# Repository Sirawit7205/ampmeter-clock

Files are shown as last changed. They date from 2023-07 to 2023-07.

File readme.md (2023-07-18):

# Ammeter Clock Controller

This is an open-source KiCAD 5 design files for a logic chips-driven clock that output time on three ammeters.

## Pictures

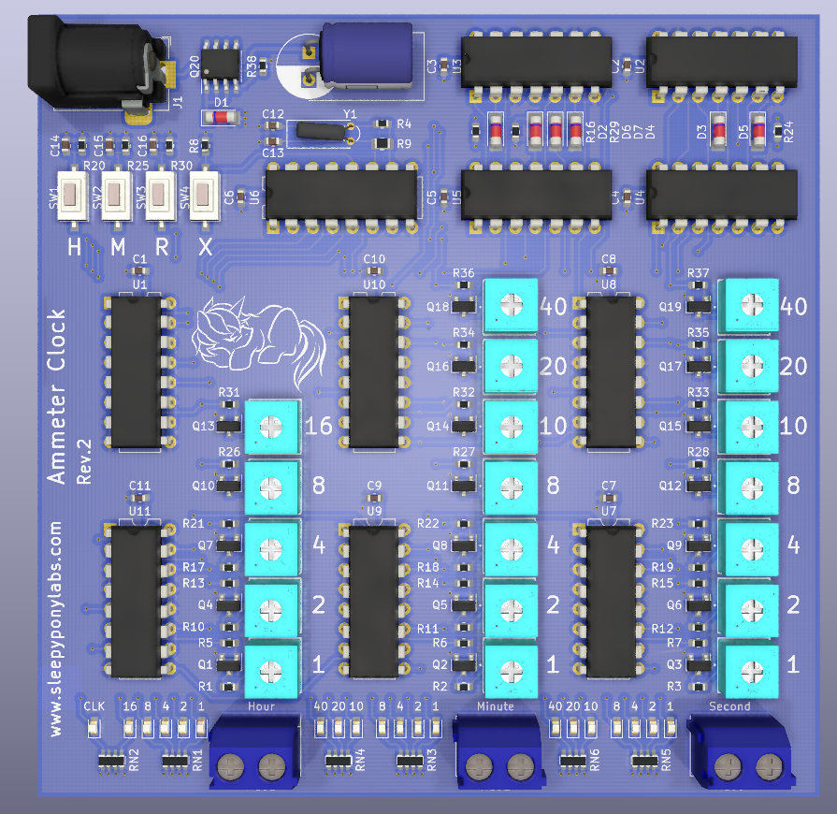
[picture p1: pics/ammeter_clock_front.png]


## Features

This is a unique clock that will certainly impress people around you.

- Ammeter Output
	- Shows hour, minute, and second on three ammeters.
	- Works with both analog and digital meters.
- Quartz Crystal-driven Clock with CD4060 IC
- Design with logic ICs. Only need 11 chips for the circuit to work.
- Set Hour, Set Min, Reset, and Clock Halt buttons
- Ammeter adjustment trimpots
- Aluminum Front Panel design available [here](https://github.com/Sirawit7205/ammeter-clock-frontpanel)

## Revisions

We are currently at Revision 2. Changelog is below:

**Revision 1 (July 2021)**
- Initial Design
- H and M buttons are swapped.

**Revision 2 (September 2021)**
- Fix H and M buttons.

## What is provided

The goal of this repository is to enable you to build this on your own as easy as possible. **The schematics, PCB design, and an interactive BOM are provided.**

Hardware is licensed under `SPDX-License-Identifier: CERN-OHL-S-2.0`

Contains no software

Documentation is licensed under `SPDX-License-Identifier: CC-BY-SA-4.0`

## Ordering

You can export gerbers from this project and order the board yourself.

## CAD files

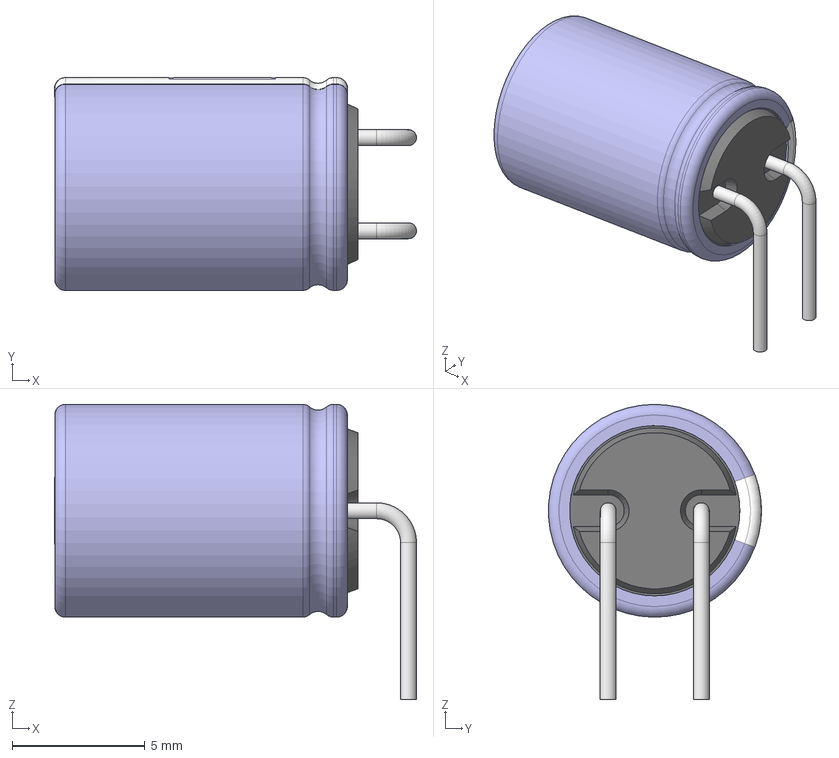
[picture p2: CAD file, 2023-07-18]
3dmodels/cap_el_horizontal_d8_h11.5_pitch3.5_w0.6.stp
13.6 x 8.00 x 11.1 mm

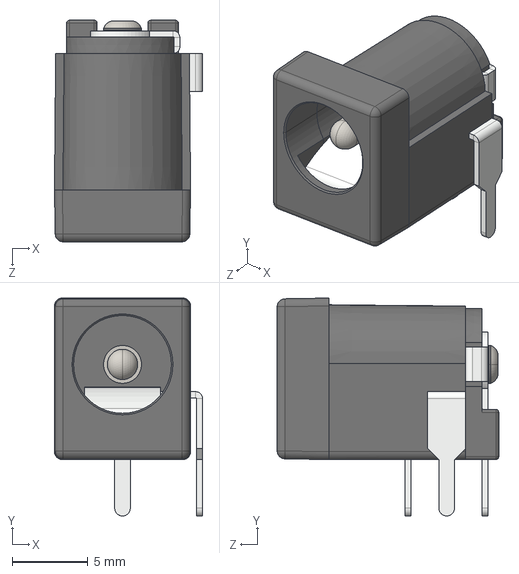
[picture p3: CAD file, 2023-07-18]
3dmodels/DC Power Jack 5.5mm x 2.1mm.STEP
9.77 x 14.4 x 14.6 mm

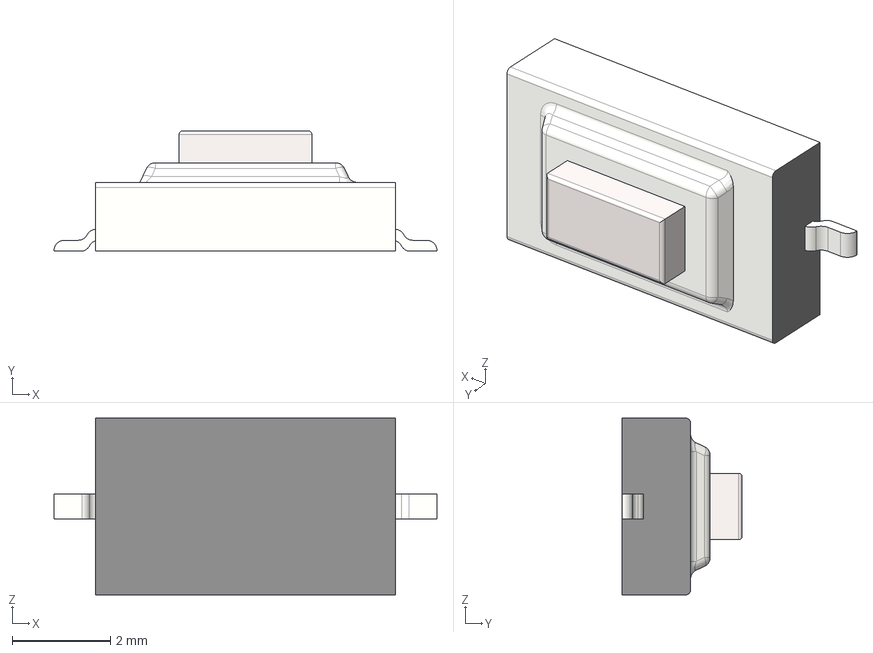
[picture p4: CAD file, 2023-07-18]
3dmodels/TactileButton(6x3,5mm)_SMD.stp
7.80 x 2.45 x 3.60 mm

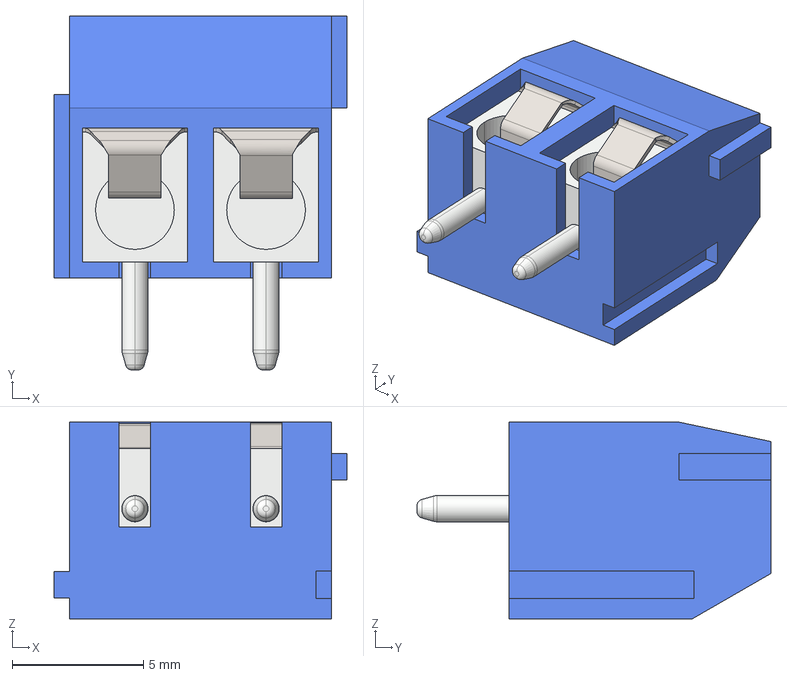
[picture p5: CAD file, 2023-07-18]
3dmodels/TE_1776244-2.STEP
11.2 x 13.5 x 7.50 mm

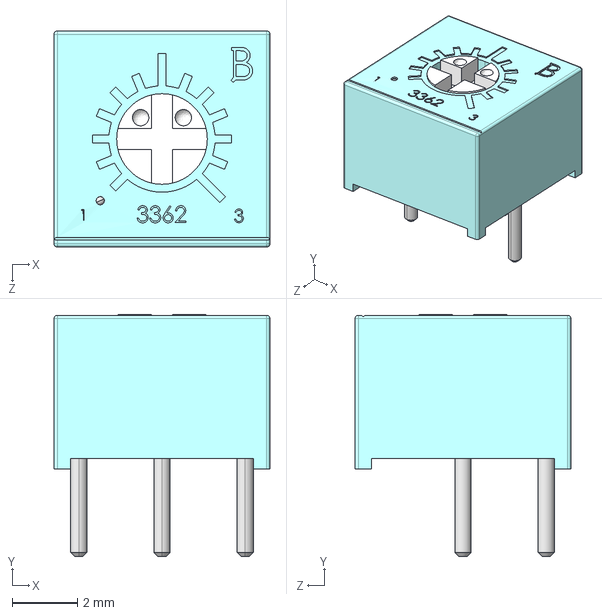
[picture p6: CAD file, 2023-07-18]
3dmodels/3362P-1-102LF.STEP
6.60 x 7.40 x 6.60 mm

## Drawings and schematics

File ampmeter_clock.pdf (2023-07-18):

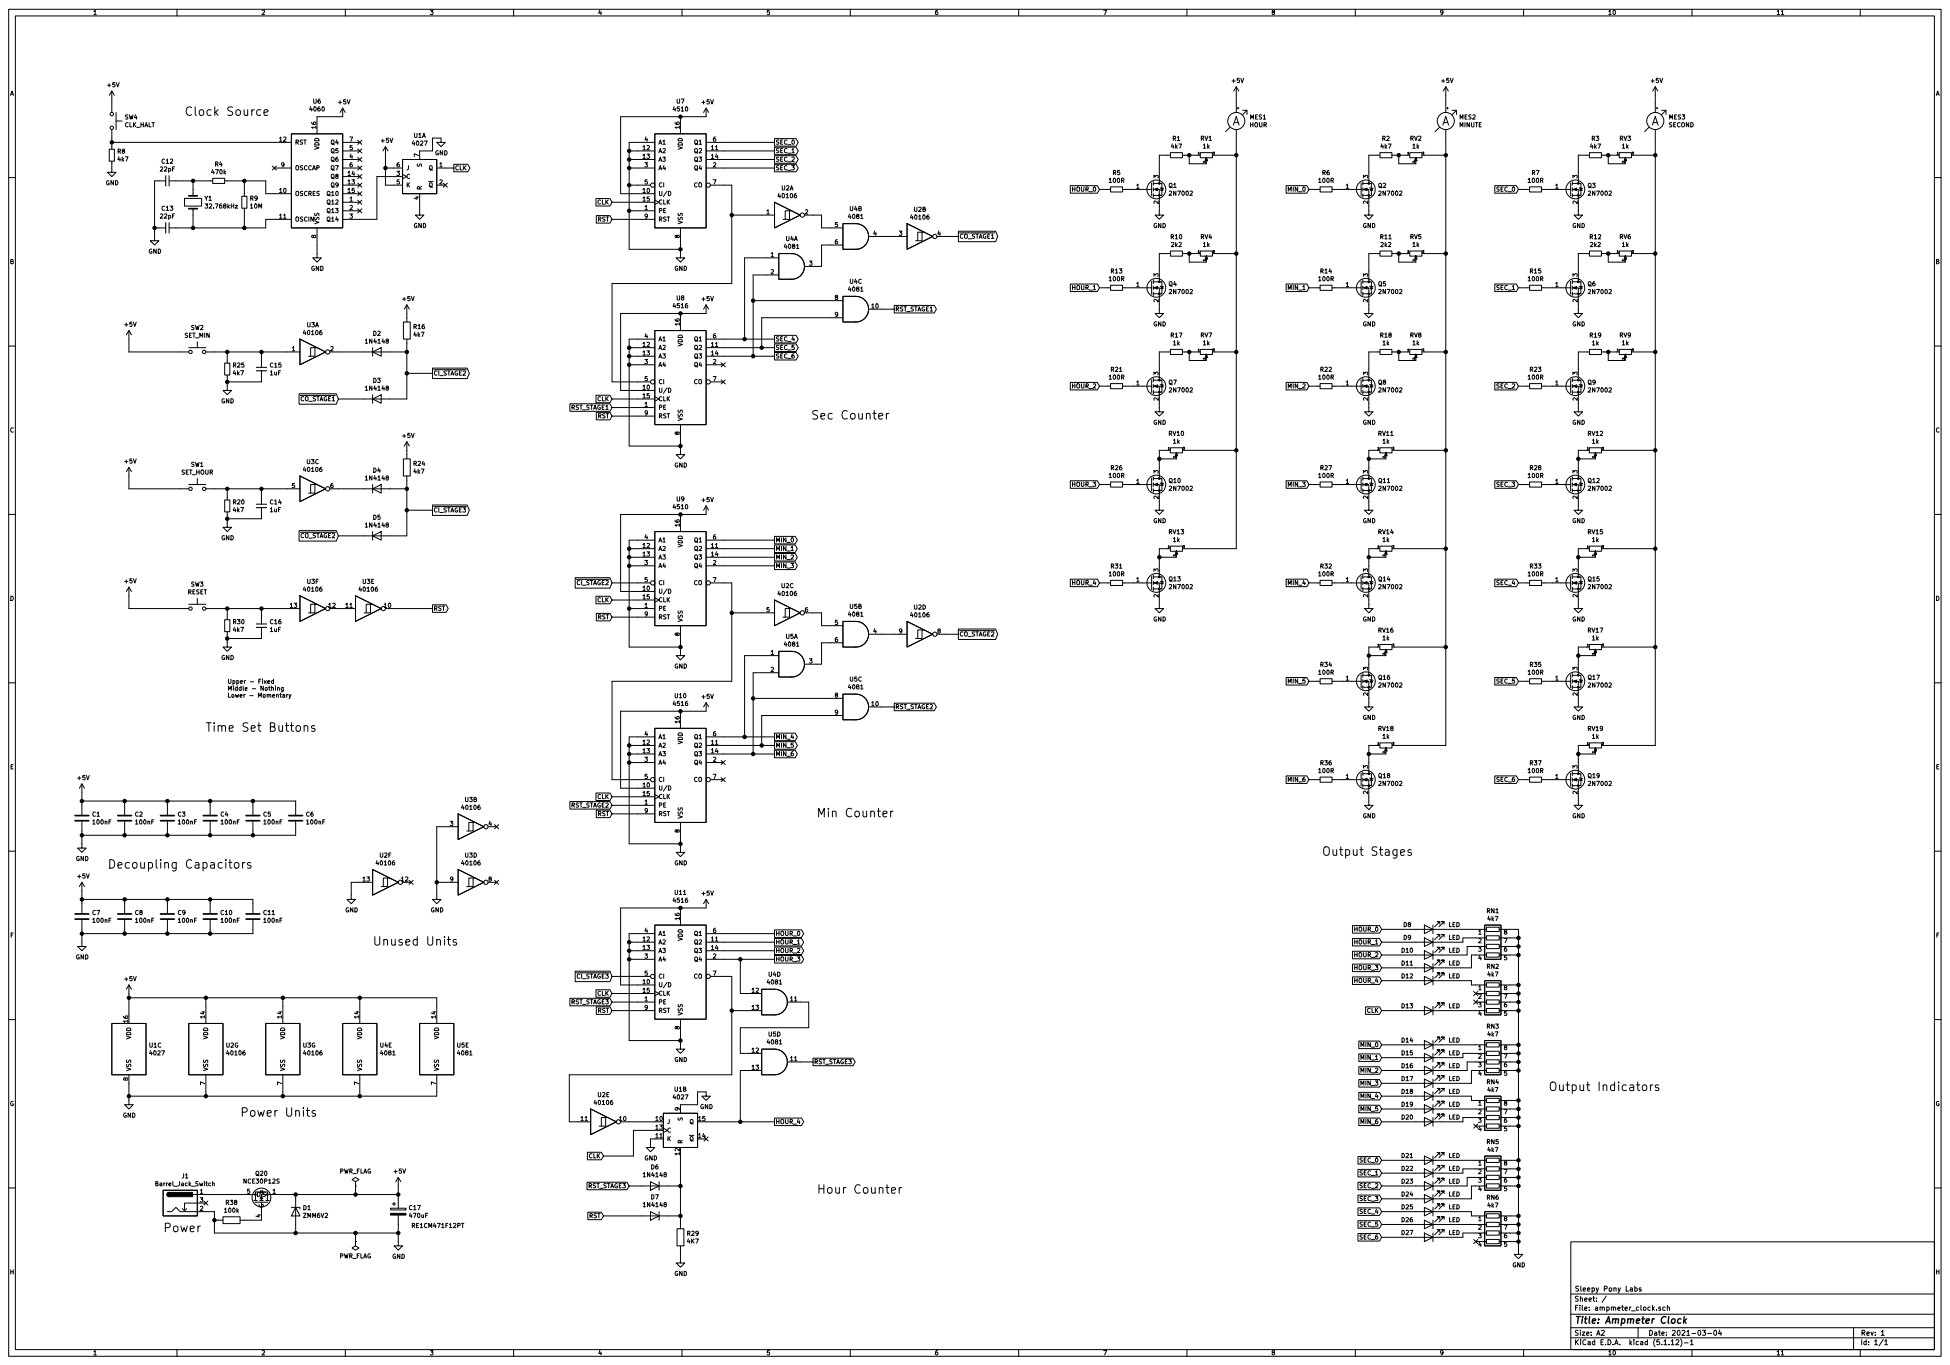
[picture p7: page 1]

File: ampmeter_clock.sch Sheet: / Sleepy Pony Labs A
GND

Id: 1/1 Title: Ampmeter Clock

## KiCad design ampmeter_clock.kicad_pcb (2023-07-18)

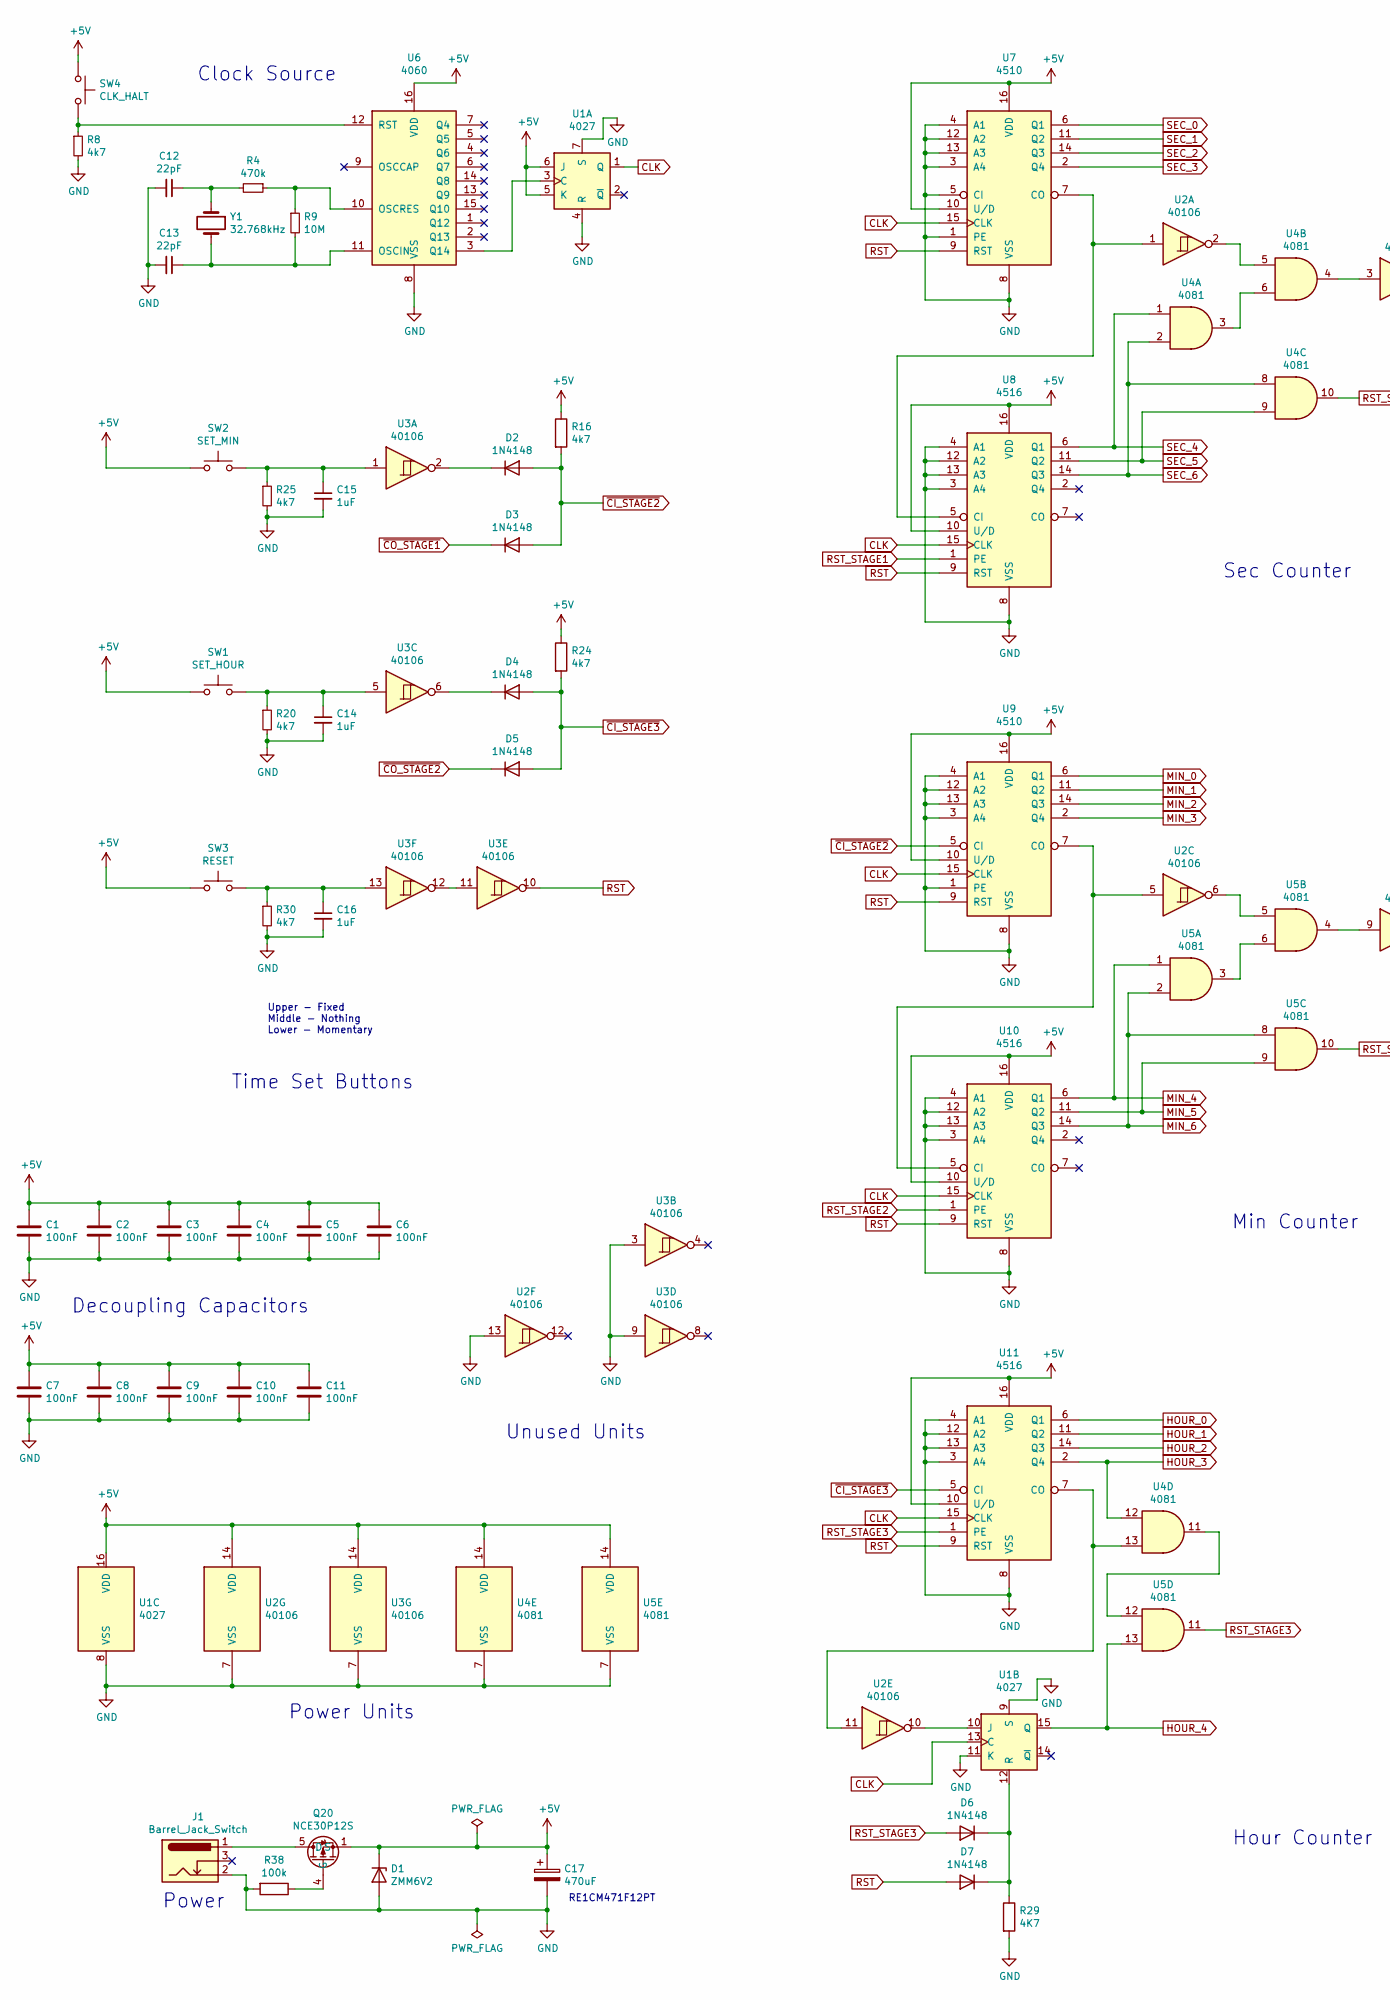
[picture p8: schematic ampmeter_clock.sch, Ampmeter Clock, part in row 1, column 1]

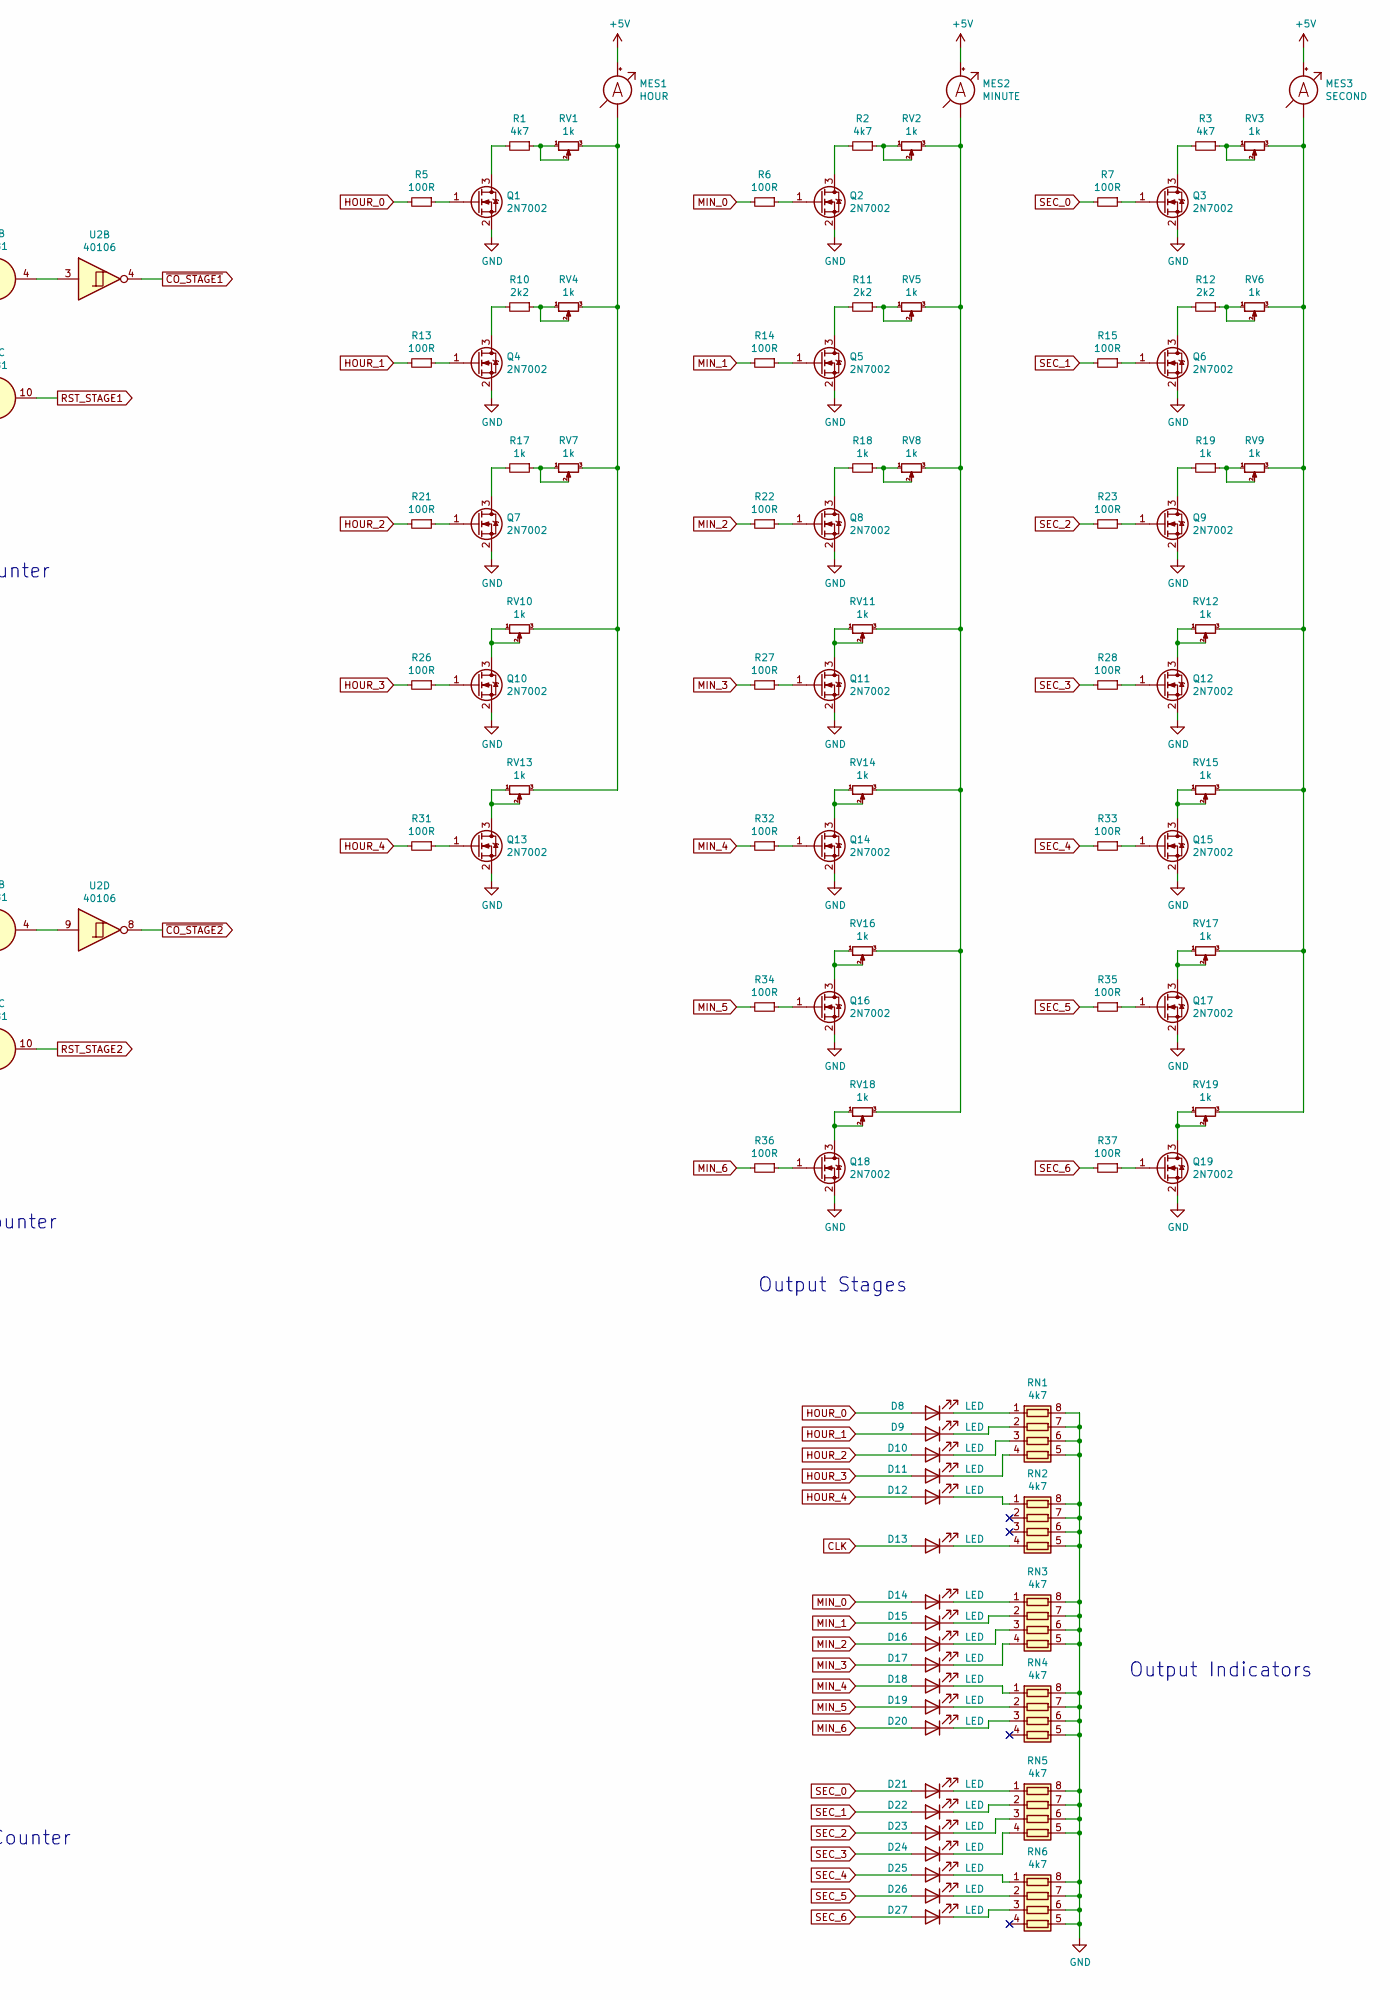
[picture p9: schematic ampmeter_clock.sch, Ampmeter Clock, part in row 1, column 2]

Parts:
C1, C2, C3, C4, C5, C6, C7, C8, C9, C10, C11: 100nF; C_0603_1608Metric
C12, C13: 22pF; C_0603_1608Metric
C14, C15, C16: 1uF; C_0603_1608Metric
C17: 470uF; CP_Radial_D8.0mm_P3.50mm
D1: ZMM6V2; D_MiniMELF
D2, D3, D4, D5, D6, D7: 1N4148; D_MiniMELF
D8, D9, D10, D11, D12, D13, D14, D15, D16, D17, D18, D19, D20, D21, D22, D23, D24, D25, D26, D27: LED; LED_0603_1608Metric
J1: Barrel_Jack_Switch; BarrelJack_Horizontal
MES1: HOUR; TerminalBlock_bornier-2_P5.08mm
MES2: MINUTE; TerminalBlock_bornier-2_P5.08mm
MES3: SECOND; TerminalBlock_bornier-2_P5.08mm
Q1, Q2, Q3, Q4, Q5, Q6, Q7, Q8, Q9, Q10, Q11, Q12, Q13, Q14, Q15, Q16, Q17, Q18, Q19: 2N7002; SOT-23
Q20: NCE30P12S; SOIC-8_3.9x4.9mm_P1.27mm
R1, R2, R3, R8, R16, R20, R24, R25, R30: 4k7; R_0603_1608Metric
R4: 470k; R_0603_1608Metric
R5, R6, R7, R13, R14, R15, R21, R22, R23, R26, R27, R28, R31, R32, R33, R34, R35, R36, R37: 100R; R_0603_1608Metric
R9: 10M; R_0805_2012Metric
R10, R11, R12: 2k2; R_0603_1608Metric
R17, R18, R19: 1k; R_0603_1608Metric
R29: 4K7; R_0603_1608Metric
R38: 100k; R_0603_1608Metric
RN1, RN2, RN3, RN4, RN5, RN6: 4k7; R_Array_Convex_4x0603
RV1, RV2, RV3, RV4, RV5, RV6, RV7, RV8, RV9, RV10, RV11, RV12, RV13, RV14, RV15, RV16, RV17, RV18, RV19: 1k; 3362P_1
SW1: SET_HOUR; TS-1101
SW2: SET_MIN; TS-1101
SW3: RESET; TS-1101
SW4: CLK_HALT; TS-1101
U1: 4027; DIP-16_W7.62mm
U2, U3: 40106; DIP-14_W7.62mm
U4, U5: 4081; DIP-14_W7.62mm
U6: 4060; DIP-16_W7.62mm
U7, U9: 4510; DIP-16_W7.62mm
U8, U10, U11: 4516; DIP-16_W7.62mm
Y1: 32.768kHz; Crystal_Round_D2.0mm_Vertical

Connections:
+5V: C1.1, C2.1, C3.1, C4.1, C5.1, C6.1, C7.1, C8.1, C9.1, C10.1, C11.1, C17.1, D1.1 (K), MES1.2 (+), MES2.2 (+), MES3.2 (+), Q20.1 (S), Q20.2 (S), Q20.3 (S), R16.1, R24.1, SW1.1, SW2.1, SW3.1, SW4.1, U1.5 (K), U1.6 (J), U1.16 (VDD), U2.14 (VDD), U3.14 (VDD), U4.14 (VDD), U5.14 (VDD), U6.16 (VDD), U7.10 (U/D), U7.16 (VDD), U8.10 (U/D), U8.16 (VDD), U9.10 (U/D), U9.16 (VDD), U10.10 (U/D), U10.16 (VDD), U11.10 (U/D), U11.16 (VDD)
CLK: D13.2 (A), U1.1 (Q), U1.13 (C), U7.15 (CLK), U8.15 (CLK), U9.15 (CLK), U10.15 (CLK), U11.15 (CLK)
GND: C1.2, C2.2, C3.2, C4.2, C5.2, C6.2, C7.2, C8.2, C9.2, C10.2, C11.2, C12.2, C13.2, C14.2, C15.2, C16.2, C17.2, D1.2 (A), J1.2, Q1.2 (S), Q2.2 (S), Q3.2 (S), Q4.2 (S), Q5.2 (S), Q6.2 (S), Q7.2 (S), Q8.2 (S), Q9.2 (S), Q10.2 (S), Q11.2 (S), Q12.2 (S), Q13.2 (S), Q14.2 (S), Q15.2 (S), Q16.2 (S), Q17.2 (S), Q18.2 (S), Q19.2 (S), R8.2, R20.2, R25.2, R29.2, R30.2, R38.2, RN1.5 (R4.2), RN1.6 (R3.2), RN1.7 (R2.2), RN1.8 (R1.2), RN2.5 (R4.2), RN2.6 (R3.2), RN2.7 (R2.2), RN2.8 (R1.2), RN3.5 (R4.2), RN3.6 (R3.2), RN3.7 (R2.2), RN3.8 (R1.2), RN4.5 (R4.2), RN4.6 (R3.2), RN4.7 (R2.2), RN4.8 (R1.2), RN5.5 (R4.2), RN5.6 (R3.2), RN5.7 (R2.2), RN5.8 (R1.2), RN6.5 (R4.2), RN6.6 (R3.2), RN6.7 (R2.2), RN6.8 (R1.2), U1.4 (R), U1.7 (S), U1.8 (VSS), U1.9 (S), U1.11 (K), U2.7 (VSS), U2.13, U3.3, U3.7 (VSS), U3.9, U4.7 (VSS), U5.7 (VSS), U6.8 (VSS), U7.1 (PE), U7.3 (A4), U7.4 (A1), U7.5 (CI), U7.8 (VSS), U7.12 (A2), U7.13 (A3), U8.3 (A4), U8.4 (A1), U8.8 (VSS), U8.12 (A2), U8.13 (A3), U9.1 (PE), U9.3 (A4), U9.4 (A1), U9.8 (VSS), U9.12 (A2), U9.13 (A3), U10.3 (A4), U10.4 (A1), U10.8 (VSS), U10.12 (A2), U10.13 (A3), U11.3 (A4), U11.4 (A1), U11.8 (VSS), U11.12 (A2), U11.13 (A3)
HOUR_0: D8.2 (A), R5.2, U11.6 (Q1)
HOUR_1: D9.2 (A), R13.2, U11.11 (Q2)
HOUR_2: D10.2 (A), R21.2, U11.14 (Q3)
HOUR_3: D11.2 (A), R26.2, U4.12, U11.2 (Q4)
HOUR_4: D12.2 (A), R31.2, U1.15 (Q), U5.13
MIN_0: D14.2 (A), R6.2, U9.6 (Q1)
MIN_1: D15.2 (A), R14.2, U9.11 (Q2)
MIN_2: D16.2 (A), R22.2, U9.14 (Q3)
MIN_3: D17.2 (A), R27.2, U9.2 (Q4)
MIN_4: D18.2 (A), R32.2, U5.1, U10.6 (Q1)
MIN_5: D19.2 (A), R34.2, U5.9, U10.11 (Q2)
MIN_6: D20.2 (A), R36.2, U5.2, U5.8, U10.14 (Q3)
unnamed: C12.1, R4.2, Y1.1
unnamed: C13.1, R9.2, U6.11 (OSCIN), Y1.2
unnamed: C14.1, R20.1, SW1.2, U3.5
unnamed: C15.1, R25.1, SW2.2, U3.1
unnamed: C16.1, R30.1, SW3.2, U3.13
unnamed: D2.1 (K), U3.2
unnamed: D4.1 (K), U3.6
unnamed: D6.1 (K), D7.1 (K), R29.1, U1.12 (R)
unnamed: D8.1 (K), RN1.1 (R1.1)
unnamed: D9.1 (K), RN1.2 (R2.1)
unnamed: D10.1 (K), RN1.3 (R3.1)
unnamed: D11.1 (K), RN1.4 (R4.1)
unnamed: D12.1 (K), RN2.1 (R1.1)
unnamed: D13.1 (K), RN2.4 (R4.1)
unnamed: D14.1 (K), RN3.1 (R1.1)
unnamed: D15.1 (K), RN3.2 (R2.1)
unnamed: D16.1 (K), RN3.3 (R3.1)
unnamed: D17.1 (K), RN3.4 (R4.1)
unnamed: D18.1 (K), RN4.1 (R1.1)
unnamed: D19.1 (K), RN4.2 (R2.1)
unnamed: D20.1 (K), RN4.3 (R3.1)
unnamed: D21.1 (K), RN5.1 (R1.1)
unnamed: D22.1 (K), RN5.2 (R2.1)
unnamed: D23.1 (K), RN5.3 (R3.1)
unnamed: D24.1 (K), RN5.4 (R4.1)
unnamed: D25.1 (K), RN6.1 (R1.1)
unnamed: D26.1 (K), RN6.2 (R2.1)
unnamed: D27.1 (K), RN6.3 (R3.1)
unnamed: J1.1, Q20.5 (D), Q20.6 (D), Q20.7 (D), Q20.8 (D)
unnamed: MES1.1 (-), RV1.3, RV4.3, RV7.3, RV10.3, RV13.3
unnamed: MES2.1 (-), RV2.3, RV5.3, RV8.3, RV11.3, RV14.3, RV16.3, RV18.3
unnamed: MES3.1 (-), RV3.3, RV6.3, RV9.3, RV12.3, RV15.3, RV17.3, RV19.3
unnamed: Q1.1 (G), R5.1
unnamed: Q1.3 (D), R1.2
unnamed: Q2.1 (G), R6.1
unnamed: Q2.3 (D), R2.2
unnamed: Q3.1 (G), R7.1
unnamed: Q3.3 (D), R3.2
unnamed: Q4.1 (G), R13.1
unnamed: Q4.3 (D), R10.2
unnamed: Q5.1 (G), R14.1
unnamed: Q5.3 (D), R11.2
unnamed: Q6.1 (G), R15.1
unnamed: Q6.3 (D), R12.2
unnamed: Q7.1 (G), R21.1
unnamed: Q7.3 (D), R17.2
unnamed: Q8.1 (G), R22.1
unnamed: Q8.3 (D), R18.2
unnamed: Q9.1 (G), R23.1
unnamed: Q9.3 (D), R19.2
unnamed: Q10.1 (G), R26.1
unnamed: Q10.3 (D), RV10.1, RV10.2
unnamed: Q11.1 (G), R27.1
unnamed: Q11.3 (D), RV11.1, RV11.2
unnamed: Q12.1 (G), R28.1
unnamed: Q12.3 (D), RV12.1, RV12.2
unnamed: Q13.1 (G), R31.1
unnamed: Q13.3 (D), RV13.1, RV13.2
unnamed: Q14.1 (G), R32.1
unnamed: Q14.3 (D), RV14.1, RV14.2
unnamed: Q15.1 (G), R33.1
unnamed: Q15.3 (D), RV15.1, RV15.2
unnamed: Q16.1 (G), R34.1
unnamed: Q16.3 (D), RV16.1, RV16.2
unnamed: Q17.1 (G), R35.1
unnamed: Q17.3 (D), RV17.1, RV17.2
unnamed: Q18.1 (G), R36.1
unnamed: Q18.3 (D), RV18.1, RV18.2
unnamed: Q19.1 (G), R37.1
unnamed: Q19.3 (D), RV19.1, RV19.2
unnamed: Q20.4 (G), R38.1
unnamed: R1.1, RV1.1, RV1.2
unnamed: R2.1, RV2.1, RV2.2
unnamed: R3.1, RV3.1, RV3.2
unnamed: R4.1, R9.1, U6.10 (OSCRES)
unnamed: R8.1, SW4.2, U6.12 (RST)
unnamed: R10.1, RV4.1, RV4.2
unnamed: R11.1, RV5.1, RV5.2
unnamed: R12.1, RV6.1, RV6.2
unnamed: R17.1, RV7.1, RV7.2
unnamed: R18.1, RV8.1, RV8.2
unnamed: R19.1, RV9.1, RV9.2
unnamed: U1.3 (C), U6.3 (Q14)
unnamed: U1.10 (J), U2.10
unnamed: U2.1, U7.7 (CO), U8.5 (CI)
unnamed: U2.2, U4.5
unnamed: U2.3, U4.4
unnamed: U2.6, U5.5
unnamed: U2.9, U5.4
unnamed: U3.11, U3.12
unnamed: U4.3, U4.6
unnamed: U4.11, U5.12
unnamed: U5.3, U5.6
unnamed: U2.5, U9.7 (CO), U10.5 (CI)
unnamed: U2.11, U4.13, U11.7 (CO)
RST: D7.2 (A), U3.10, U7.9 (RST), U8.9 (RST), U9.9 (RST), U10.9 (RST), U11.9 (RST)
RST_STAGE1: U4.10, U8.1 (PE)
RST_STAGE2: U5.10, U10.1 (PE)
RST_STAGE3: D6.2 (A), U5.11, U11.1 (PE)
SEC_0: D21.2 (A), R7.2, U7.6 (Q1)
SEC_1: D22.2 (A), R15.2, U7.11 (Q2)
SEC_2: D23.2 (A), R23.2, U7.14 (Q3)
SEC_3: D24.2 (A), R28.2, U7.2 (Q4)
SEC_4: D25.2 (A), R33.2, U4.1, U8.6 (Q1)
SEC_5: D26.2 (A), R35.2, U4.9, U8.11 (Q2)
SEC_6: D27.2 (A), R37.2, U4.2, U4.8, U8.14 (Q3)
~CI_STAGE2: D2.2 (A), D3.2 (A), R16.2, U9.5 (CI)
~CI_STAGE3: D4.2 (A), D5.2 (A), R24.2, U11.5 (CI)
~CO_STAGE1: D3.1 (K), U2.4
~CO_STAGE2: D5.1 (K), U2.8

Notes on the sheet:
Upper - Fixed Middle - Nothing Lower - Momentary
Clock Source
Time Set Buttons
Sec Counter
Min Counter
Hour Counter
Power Units
Unused Units
Output Stages
Decoupling Capacitors
Power
Output Indicators
RE1CM471F12PT

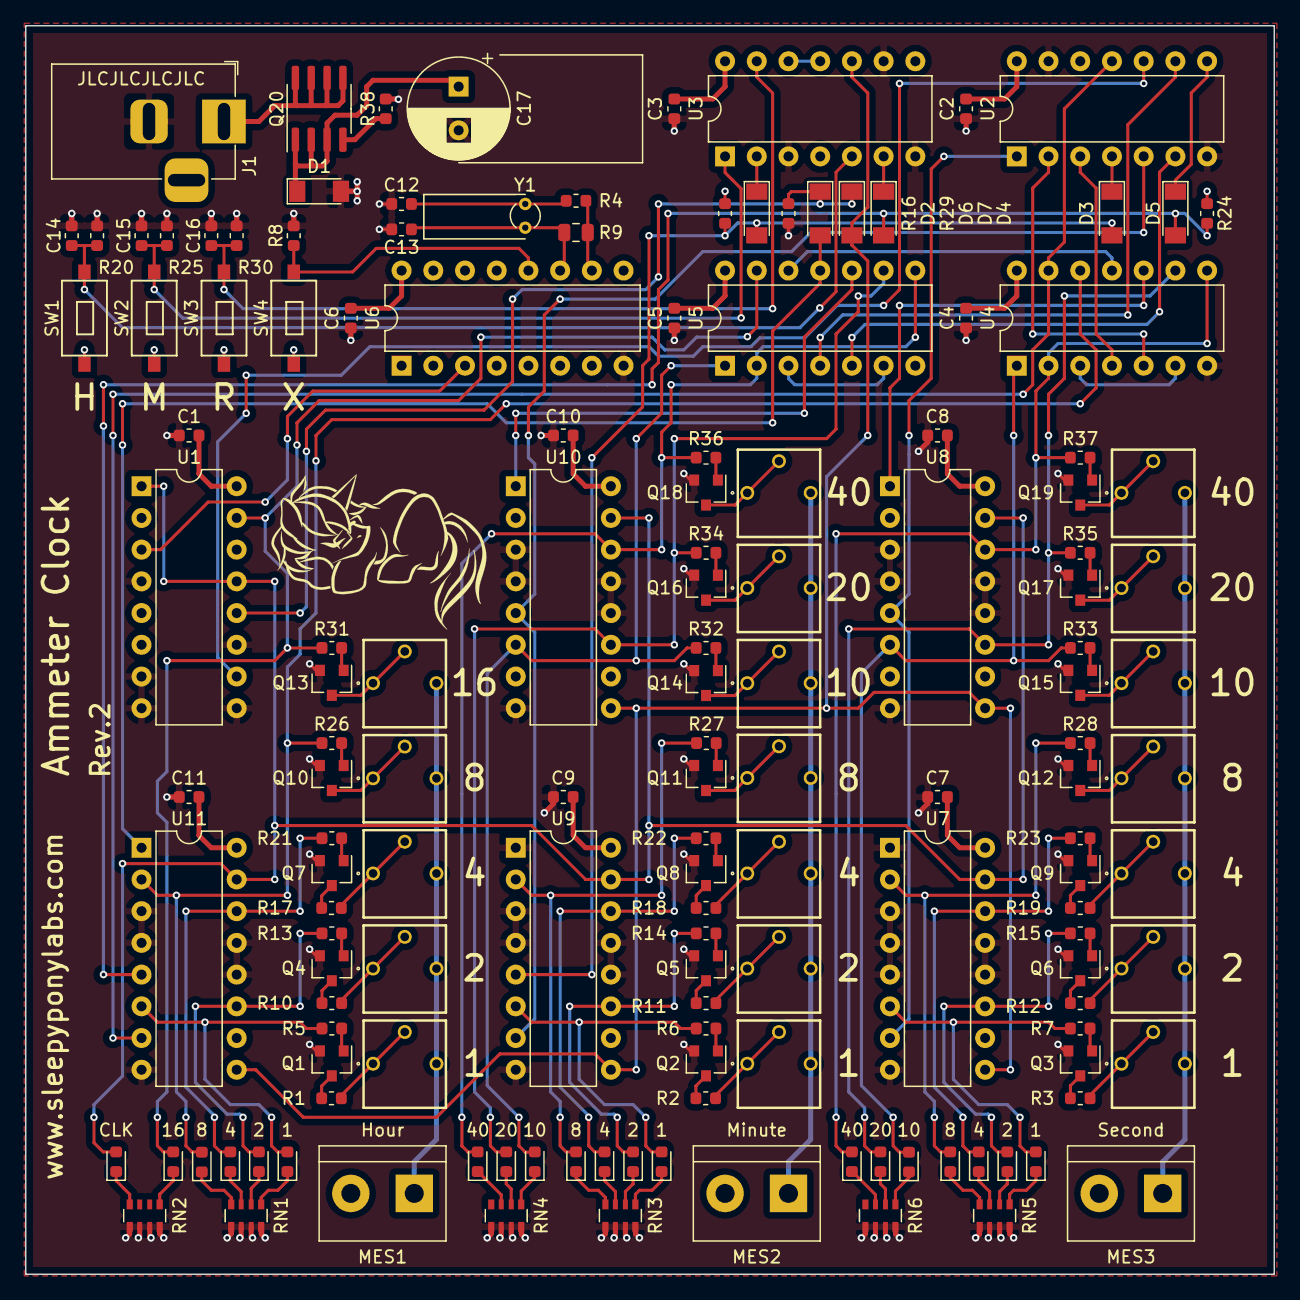
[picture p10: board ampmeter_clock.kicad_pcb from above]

Board: 4 copper layers, 100.0 x 100.0 mm, 147 parts (0 on the bottom side), 125 nets.

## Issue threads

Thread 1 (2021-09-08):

Hardcoded path in sym-lib-table

hevanaa, 2021-09-08:
Please change the hard-coded library path in sym-lib-table to:

`uri ${KIPRJMOD}/libs/ampmeter_clock.lib`

But what an awesome project! I really like it.

Sirawit7205, 2021-09-08:
Hello. Thanks for picking this up! It has been fixed, along with the swapped buttons.

Closed 2021-09-08.

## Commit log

2021-06-16 Fix bugs
    [ampmeter_clock.sch]
2021-06-19 Component Placement
    [3362P-1-102LF.STEP, DC Power Jack 5.5mm x 2.1mm.STEP, TE_1776244-2.STEP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]
2021-07-01 PCB done
    [ampmeter_clock-B_Cu.gbr, ampmeter_clock-B_Mask.gbr, ampmeter_clock-B_SilkS.gbr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]
2021-07-17 Fix PCB Edge, add ibom
    [ampmeter_clock.kicad_pcb]
2021-09-08 Fix swapped H and M buttons and misc traces adjustments
    [ampmeter_clock-B_Cu.gbr, ampmeter_clock-B_Mask.gbr, ampmeter_clock-B_SilkS.gbr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]
2023-06-16 Update schematics PDF
2023-07-18 Fix silk, generate ibom for rev 2
    [ampmeter_clock.kicad_pcb, ampmeter_clock.sch]
